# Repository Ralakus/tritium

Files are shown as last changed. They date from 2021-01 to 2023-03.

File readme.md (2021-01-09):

# Tritium Project
An open source RISC based balanced ternary computer

## What does balanced ternary mean?
Normal computers process data in binary which means two states, a one and a zero. Ternary is similar except operating on three states. In balanced ternary, there is a negative (i), neutral (0), and positive (1) which means numbers are naturally signed thus simplifying the architecture and general logic. Ternary also has the best radix efficiency for any integer base of 1.0046 where binary is 1.0615 with base e 1.0000 being the most efficient. A 'trit' is the ternary analogue of a bit which stores an i,0, or 1. 

## Has this been done before?
There are many projects similar to this but they either haven't gone very far, closed source, or dead. The main inspiration for this computer is the Russian Setun computer, more specifically the Setun-70 which has an 18 trit word and 81 words of memory with a magnetic drum holding more memory. 

## Variants
9, 27, 54, and maybe even 81 trit word variants will be made with a similar architecture. The 9 trit architecture being dubbed 'Tritium-9' will be made first as an experiment and prototype.

## Directory Structure
* architecture - contains documentation about the architecture of each tritium variant
* pcbs - contains all schematics and each revision of the custom pcb designs
* simulation - contains tests setup to simulate basic logic and other various circuitry test using ngspice
* tritium - contains the overall schematic of each tritium variant

## Tritium-9
### Design Goals
* Around or less than $250
* iiiiiiii to i11111111 being binary EEPROM to run a program off of with 0iiiiiiii to 111111111 being SRAM thus having the full 19683 tryte address space
* Have the ability to communicate with binary components
* Use easily sourcable parts

### Current Status
Tested each rev.0 pcb and posted results. Continuing on designing the alu

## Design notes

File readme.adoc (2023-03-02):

= Tritium Project
An open source RISC based balanced ternary computer research project

== This is a research project
This project is not fully intended to get a perfectly functional computer out to the market, but rather, it is intended to get the concept of ternary computing out to the public so more people will start researching ternary computing as an alternative to binary computing. 

== What does balanced ternary mean?
Normal computers process data in binary which means two states, a one and a zero. Ternary is similar except operating on three states. In balanced ternary, there is a negative (i), neutral (0), and positive (1) which means numbers are naturally signed thus simplifying the architecture and general logic. Ternary also has the best radix efficiency for any integer base of 1.0046 where binary is 1.0615 with base e, 1.0000 being the most efficient. A 'trit' is the ternary analogue of a bit which stores an i (-1), 0, or 1. 

== Has this been done before?
There are many projects similar to this but they either haven't gone very far, closed source and secretive, or dead. The main inspiration for this project is the Russian Setun computer, more specifically the Setun-70 which has an 18 trit word and 81 words of memory with a magnetic drum holding more memory. 

== Directory Structure
* docs - contains documentation on the project and lab results
* kicad - contains the kicad project files for each part
** components - contains all complex multigate circuits
** gates - contains all ternary gates and their panelized PCBs
** logic - contains logical schematics of circuits using logic gates instead of transistors
* library - contains all of the kicad libraries such as the footprints, spice models, and symbols

== Possible final computer variants
=== Tritium-6
A 6-trit computer that is cheap and simple to make where the instructions more closely resemble microcode rather than instructions.

==== Design Goals
* Around or less than $250 in components
* Have the ability to communicate with binary components
* Use easily sourcable parts
* One clock cycle per instruction

=== Tritium-27
A full scale computer that mirrors RISC-V in capability and instruction set.

==== Design Goals
* Around or less than $1000 in components
* Have the ability to communicate with binary components
* Use easily sourcable parts

== Current Status
The gates from OSHPark came but I've hit a bit of a time and financial crunch so I don't quite have the time to work on the physical part of the project. I'm currently working with a local college professor to write up a better ISA than the previous versions for a machine that I could follow that wouldn't be too expensive to implement. I've decided that the decoding logic for the control module may be too expensive to implement so I will see if I can use a binary EEPROM using encoded balanced ternary as a lookup table and then convert the inputs back to native balanced ternary.

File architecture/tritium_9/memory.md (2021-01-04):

# Tritium-9 Memory Mapping

## Memory regions
There are three memory regions:
* iiiiiiiii to i11111111 is mapped to the EEPROM and memory mapped IO
* 0iiiiiiii to 011111111 is mapped to persistent user usable RAM
* 1iiiiiiii to 111111111 is mapped to a memory page

## Memory pages
The page is controlled by the control register `page`. The pages can be mapped to any hardware thus giving lots of expandability outside of the 9-trit address space.

## RAM
As a first prototype, all RAM will be static RAM due to the low quantity needed but in the future, DRAM will be experimented with and possibly a native ternary DRAM module will be developed

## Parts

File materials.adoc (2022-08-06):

= Materials used in project

== PCB Manufacturing
Custom PCBs through OSHPark

== Power Supply
Meanwell RT-50A

== Gates
Complementary Pair MOSFET - BSS8402DW-7-F +
12k 0603 SMD Resistors

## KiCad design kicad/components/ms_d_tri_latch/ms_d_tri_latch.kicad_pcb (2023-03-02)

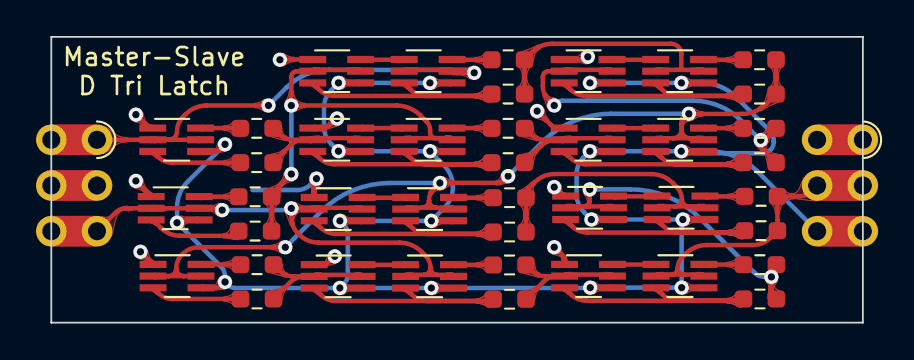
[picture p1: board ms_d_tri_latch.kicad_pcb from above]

Board: 2 copper layers, 45.1 x 15.9 mm, 43 parts (0 on the bottom side), 45 nets.

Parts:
J1, J2: Conn_01x03; Hybrid_Castellation_1x03_P2.54
Q1, Q2, Q3, Q4, Q5, Q6, Q7, Q8, Q9, Q10, Q11, Q12, Q13, Q14, Q15, Q16, Q17, Q18, Q19: BSS8402DW-7-F; SOT-363_SC-70-6_Handsoldering
R1, R2, R3, R4, R5, R6, R7, R8, R9, R10, R11, R12, R13, R14, R15, R16, R17, R18, R19, R20, R21, R22: 12k; R_0603_1608Metric_Pad0.98x0.95mm_HandSolder

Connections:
/Inverter2/Nti: Q19.6 (D), R22.2
/Inverter2/Out: Q14.2 (G), Q14.5 (G), Q15.2 (G), Q15.5 (G), R21.2, R22.1
/Inverter2/Pti: Q19.3 (D), R21.1
/d_latch1/Antimin4/B: Q3.2 (G), Q3.5 (G), R19.2, R20.1
/d_latch1/Antimin5/Out: Q4.2 (G), Q4.5 (G), R7.2, R8.1
/d_latch1/Antimin7/B: Q18.2 (G), Q18.5 (G), R1.2, R2.1
/d_latch1/Inverter1/Nti: Q1.6 (D), R2.2
/d_latch1/Inverter1/Pti: Q1.3 (D), R1.1
/d_latch1/~Q: Q5.2 (G), Q5.5 (G), R3.2, R4.1
/d_latch/Antimin4/B: Q10.2 (G), Q10.5 (G), R17.2, R18.1
/d_latch/Antimin5/Out: Q11.2 (G), Q11.5 (G), R15.2, R16.1
/d_latch/Antimin7/B: Q16.2 (G), Q16.5 (G), R9.2, R10.1
/d_latch/Inverter1/Nti: Q8.6 (D), R10.2
/d_latch/Inverter1/Pti: Q8.3 (D), R9.1
/d_latch/Q: Q1.2 (G), Q1.5 (G), Q6.2 (G), Q6.5 (G), Q9.2 (G), Q9.5 (G), R13.2, R14.1
/d_latch/~Q: Q12.2 (G), Q12.5 (G), R11.2, R12.1
D: J1.1, Q8.2 (G), Q8.5 (G), Q13.2 (G), Q13.5 (G)
Enable: J1.3, Q7.2 (G), Q7.5 (G), Q17.2 (G), Q17.5 (G), Q19.2 (G), Q19.5 (G)
unnamed: Q2.1 (S), Q3.6 (D)
unnamed: Q2.3 (D), Q3.3 (D), R3.1
unnamed: Q2.6 (D), R4.2
unnamed: Q4.1 (S), Q5.6 (D)
unnamed: Q4.3 (D), Q5.3 (D), R5.1
unnamed: Q4.6 (D), R6.2
unnamed: Q6.1 (S), Q7.6 (D)
unnamed: Q6.3 (D), Q7.3 (D), R7.1
unnamed: Q6.6 (D), R8.2
unnamed: Q9.6 (D), R12.2
unnamed: Q9.3 (D), Q10.3 (D), R11.1
unnamed: Q9.1 (S), Q10.6 (D)
unnamed: Q11.1 (S), Q12.6 (D)
unnamed: Q11.3 (D), Q12.3 (D), R13.1
unnamed: Q11.6 (D), R14.2
unnamed: Q13.1 (S), Q14.6 (D)
unnamed: Q13.3 (D), Q14.3 (D), R15.1
unnamed: Q13.6 (D), R16.2
unnamed: Q15.1 (S), Q16.6 (D)
unnamed: Q15.3 (D), Q16.3 (D), R17.1
unnamed: Q15.6 (D), R18.2
unnamed: Q17.1 (S), Q18.6 (D)
unnamed: Q17.3 (D), Q18.3 (D), R19.1
unnamed: Q17.6 (D), R20.2
Q: J2.2, Q2.2 (G), Q2.5 (G), R5.2, R6.1
VDD: J2.3, Q1.4 (S), Q2.4 (S), Q3.4 (S), Q4.4 (S), Q5.4 (S), Q6.4 (S), Q7.4 (S), Q8.4 (S), Q9.4 (S), Q10.4 (S), Q11.4 (S), Q12.4 (S), Q13.4 (S), Q14.4 (S), Q15.4 (S), Q16.4 (S), Q17.4 (S), Q18.4 (S), Q19.4 (S)
VSS: J1.2, J2.1, Q1.1 (S), Q3.1 (S), Q5.1 (S), Q7.1 (S), Q8.1 (S), Q10.1 (S), Q12.1 (S), Q14.1 (S), Q16.1 (S), Q18.1 (S), Q19.1 (S)

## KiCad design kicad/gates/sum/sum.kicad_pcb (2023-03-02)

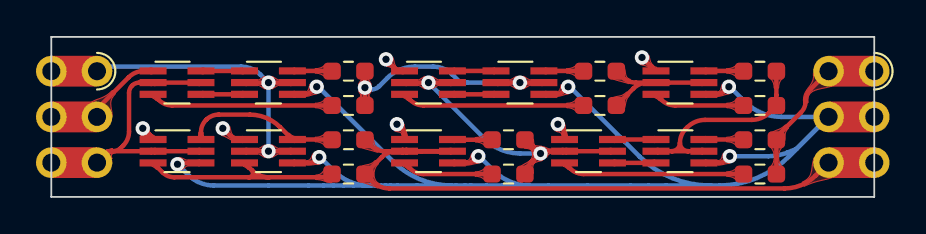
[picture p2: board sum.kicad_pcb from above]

Board: 2 copper layers, 45.7 x 8.9 mm, 24 parts (0 on the bottom side), 28 nets.

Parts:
J1, J2: Conn_01x03; Hybrid_Castellation_1x03_P2.54
Q1, Q2, Q3, Q4, Q5, Q6, Q7, Q8, Q9, Q10: BSS8402DW-7-F; SOT-363_SC-70-6_Handsoldering
R1, R2, R3, R4, R5, R6, R7, R8, R9, R10, R11, R12: 12k; R_0603_1608Metric_Pad0.98x0.95mm_HandSolder

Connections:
/Inverter BL/Nti: Q8.6 (D), R10.2
/Inverter BL/Out: Q4.2 (G), Q4.5 (G), Q6.2 (G), Q6.5 (G), R9.2, R10.1
/Inverter BL/Pti: Q8.3 (D), R9.1
/Inverter M/In: Q7.2 (G), Q7.5 (G), R3.2, R4.1
/Inverter M/Nti: Q7.6 (D), R8.2
/Inverter M/Out: Q5.2 (G), Q5.5 (G), R7.2, R8.1
/Inverter M/Pti: Q7.3 (D), R7.1
/NAny M/A: Q3.2 (G), Q3.5 (G), R1.2, R2.1
A: J1.1, Q1.2 (G), Q1.5 (G), Q9.2 (G), Q9.5 (G)
B: J1.3, Q2.2 (G), Q2.5 (G), Q10.2 (G), Q10.5 (G)
unnamed: Q1.1 (S), Q2.6 (D)
unnamed: Q1.3 (D), Q2.4 (S)
unnamed: Q1.6 (D), R2.2
unnamed: Q2.3 (D), R1.1
unnamed: Q3.1 (S), Q4.6 (D)
unnamed: Q3.3 (D), Q4.4 (S)
unnamed: Q3.6 (D), R4.2
unnamed: Q4.3 (D), R3.1
unnamed: Q5.1 (S), Q6.6 (D)
unnamed: Q5.3 (D), Q6.4 (S)
unnamed: Q5.6 (D), R6.2
unnamed: Q6.3 (D), R5.1
unnamed: Q9.3 (D), Q10.3 (D), R11.1
unnamed: Q9.6 (D), Q10.6 (D), R12.2
Sum: J2.1, R5.2, R6.1
VDD: J2.2, Q1.4 (S), Q3.4 (S), Q5.4 (S), Q7.4 (S), Q8.4 (S), Q9.4 (S), Q10.4 (S)
VSS: J1.2, Q2.1 (S), Q4.1 (S), Q6.1 (S), Q7.1 (S), Q8.1 (S), Q9.1 (S), Q10.1 (S)
~Carry: J2.3, Q8.2 (G), Q8.5 (G), R11.2, R12.1

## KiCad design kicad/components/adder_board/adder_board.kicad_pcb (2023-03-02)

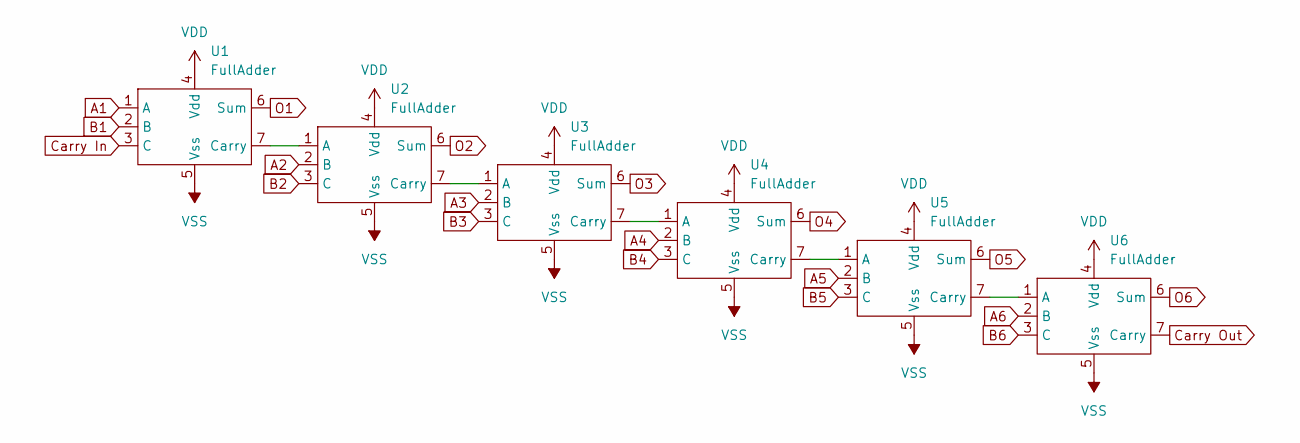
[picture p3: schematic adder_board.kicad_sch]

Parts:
U1, U2, U3, U4, U5, U6: FullAdder

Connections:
A1: U1.1 (A)
A2: U2.2 (B)
A3: U3.2 (B)
A4: U4.2 (B)
A5: U5.2 (B)
A6: U6.2 (B)
B1: U1.2 (B)
B2: U2.3 (C)
B3: U3.3 (C)
B4: U4.3 (C)
B5: U5.3 (C)
B6: U6.3 (C)
Carry In: U1.3 (C)
Carry Out: U6.7 (Carry)
unnamed: U1.7 (Carry), U2.1 (A)
unnamed: U2.7 (Carry), U3.1 (A)
unnamed: U3.7 (Carry), U4.1 (A)
unnamed: U4.7 (Carry), U5.1 (A)
unnamed: U5.7 (Carry), U6.1 (A)
O1: U1.6 (Sum)
O2: U2.6 (Sum)
O3: U3.6 (Sum)
O4: U4.6 (Sum)
O5: U5.6 (Sum)
O6: U6.6 (Sum)
VDD: U1.4 (Vdd), U2.4 (Vdd), U3.4 (Vdd), U4.4 (Vdd), U5.4 (Vdd), U6.4 (Vdd)
VSS: U1.5 (Vss), U2.5 (Vss), U3.5 (Vss), U4.5 (Vss), U5.5 (Vss), U6.5 (Vss)

Board: 2 copper layers, 6 parts (0 on the bottom side), 7 nets, no tracks yet.

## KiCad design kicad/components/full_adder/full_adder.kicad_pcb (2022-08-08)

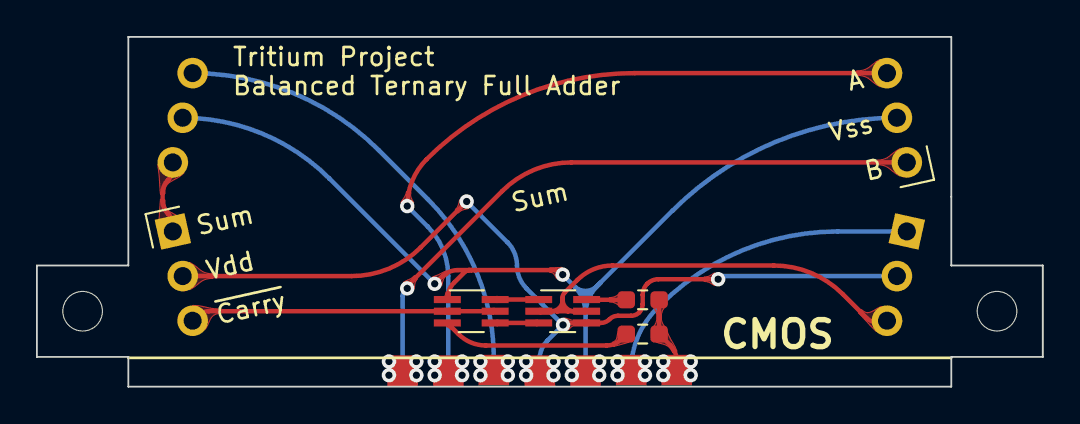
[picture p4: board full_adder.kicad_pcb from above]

Board: 2 copper layers, 55.9 x 19.4 mm, 6 parts (1 on the bottom side), 10 nets.

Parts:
Q1, Q2: BSS8402DW-7-F; SOT-363_SC-70-6_Handsoldering
R1, R2: 12k; R_0603_1608Metric_Pad0.98x0.95mm_HandSolder
U1, U2: Sum

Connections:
/NAny/A: Q1.2 (G), Q1.5 (G), U2.3 (~Carry)
/NAny/B: Q2.2 (G), Q2.5 (G), U1.3 (~Carry)
Carry: R1.2, R2.1
unnamed: Q1.1 (S), Q2.6 (D)
unnamed: Q1.3 (D), Q2.4 (S)
unnamed: Q1.6 (D), R2.2
unnamed: Q2.3 (D), R1.1
unnamed: U1.1 (Sum), U2.6 (B)
VDD: Q1.4 (S), U1.2 (Vdd), U2.2 (Vdd)
VSS: Q2.1 (S), U1.5 (Vss), U2.5 (Vss)

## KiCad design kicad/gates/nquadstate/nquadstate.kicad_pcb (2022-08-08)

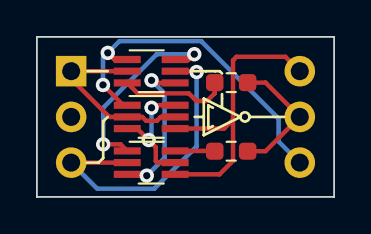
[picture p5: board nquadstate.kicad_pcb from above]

Board: 2 copper layers, 16.5 x 8.9 mm, 7 parts (0 on the bottom side), 10 nets.

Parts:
J1, J2: Conn_01x03; PinHeader_1x03_P2.54mm_Vertical_NoSilkscreen
Q1, Q2, Q3: BSS8402DW-7-F; SOT-363_SC-70-6_Handsoldering
R1, R2: 12k; R_0603_1608Metric_Pad0.98x0.95mm_HandSolder

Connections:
Gate: J1.1, Q1.2 (G), Q1.5 (G), Q3.2 (G)
In: J1.3, Q2.2 (G), Q3.5 (G)
unnamed: Q1.3 (D), Q1.6 (D), Q2.5 (G)
unnamed: Q2.1 (S), Q3.6 (D)
unnamed: Q2.3 (D), Q3.4 (S)
unnamed: Q2.6 (D), R2.2
unnamed: Q3.3 (D), R1.1
Out: J2.2, R1.2, R2.1
VDD: J2.1, Q1.4 (S), Q2.4 (S)
VSS: J2.3, Q1.1 (S), Q3.1 (S)

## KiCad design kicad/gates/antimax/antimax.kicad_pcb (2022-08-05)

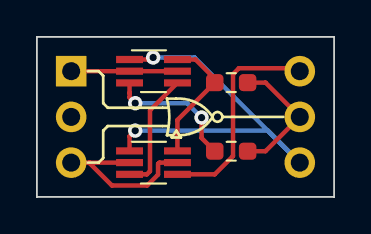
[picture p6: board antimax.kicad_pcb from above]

Board: 2 copper layers, 16.5 x 8.9 mm, 6 parts (0 on the bottom side), 8 nets.

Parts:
J1, J2: Conn_01x03; PinHeader_1x03_P2.54mm_Vertical_NoSilkscreen
Q1, Q2: BSS8402DW-7-F; SOT-363_SC-70-6_Handsoldering
R1, R2: 12k; R_0603_1608Metric_Pad0.98x0.95mm_HandSolder

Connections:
A: J1.3, Q1.2 (G), Q1.5 (G)
B: J1.1, Q2.2 (G), Q2.5 (G)
unnamed: Q1.3 (D), Q2.4 (S)
unnamed: Q1.6 (D), Q2.6 (D), R2.2
unnamed: Q2.3 (D), R1.1
Out: J2.2, R1.2, R2.1
VDD: J2.1, Q1.4 (S)
VSS: J2.3, Q1.1 (S), Q2.1 (S)

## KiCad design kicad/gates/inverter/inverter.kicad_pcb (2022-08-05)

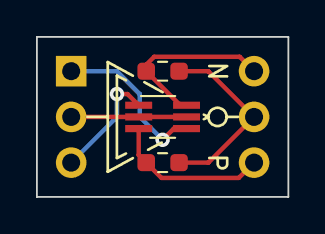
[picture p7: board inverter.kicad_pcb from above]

Board: 2 copper layers, 14.0 x 8.9 mm, 5 parts (0 on the bottom side), 6 nets.

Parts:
J1, J2: Conn_01x03; PinHeader_1x03_P2.54mm_Vertical_NoSilkscreen
Q1: BSS8402DW-7-F; SOT-363_SC-70-6_Handsoldering
R1, R2: 12k; R_0603_1608Metric_Pad0.98x0.95mm_HandSolder

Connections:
In: J1.2, Q1.2 (G), Q1.5 (G)
Nti: J2.1, Q1.6 (D), R2.2
Out: J2.2, R1.2, R2.1
Pti: J2.3, Q1.3 (D), R1.1
VDD: J1.1, Q1.4 (S)
VSS: J1.3, Q1.1 (S)

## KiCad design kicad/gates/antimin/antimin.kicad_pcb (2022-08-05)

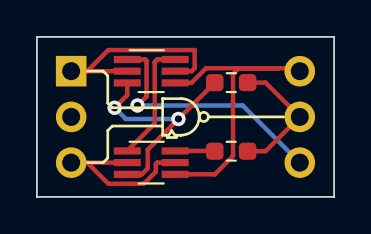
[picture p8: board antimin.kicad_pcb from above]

Board: 2 copper layers, 16.5 x 8.9 mm, 6 parts (0 on the bottom side), 8 nets.

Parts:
J1, J2: Conn_01x03; PinHeader_1x03_P2.54mm_Vertical_NoSilkscreen
Q1, Q2: BSS8402DW-7-F; SOT-363_SC-70-6_Handsoldering
R1, R2: 12k; R_0603_1608Metric_Pad0.98x0.95mm_HandSolder

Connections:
A: J1.3, Q1.2 (G), Q1.5 (G)
B: J1.1, Q2.2 (G), Q2.5 (G)
unnamed: Q1.1 (S), Q2.6 (D)
unnamed: Q1.3 (D), Q2.3 (D), R1.1
unnamed: Q1.6 (D), R2.2
Out: J2.2, R1.2, R2.1
VDD: J2.1, Q1.4 (S), Q2.4 (S)
VSS: J2.3, Q2.1 (S)

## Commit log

2020-12-07 binary converter
    [and.sch, antimax.sch, binary_conversion.kicad_pcb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]
2020-12-18 ternary adders, switches, and cyclers
    [addition.kicad_pcb, addition.sch, alu.sch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]
2020-12-18 remove nconensus gate from sum gate, removed .sch-bak and cache files
    [addition.sch, full_adder.sch, half_adder.sch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]
2020-12-18 lowered transistor count for sum gate
    [addition.sch, full_adder.sch, half_adder.sch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]
2020-12-18 added flat schematic for full adder
    [addition.sch, flat_schematic.sch, full_adder.sch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]
2020-12-20 added pcbs for each gate
    [antimax.kicad_pcb, antimax.sch, antimin.kicad_pcb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]
2020-12-23 added KiCad library for ternary gates and went from header pins and sockets to castellated edge pcbs
    [alu.sch, analogue_switch.sch, and.sch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]
2020-12-27 added ngspice models for each gate symbol
    [addition.sch, antimax.sch, full_adder.sch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]
2020-12-27 updated readme.md and materials.md
2020-12-27 update readme.md to include current project status
    [addition.sch, and.sch, binary_conversion.sch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]
2020-12-28 added edge triggered triflop
    [edge_detection.kicad_pcb, edge_detection.sch, triflop.kicad_pcb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]
2020-12-28 added block diagram architecture
    [alu.sch, clock.sch, control_register.sch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]
2021-01-01 re-organized project directory and started work on ALU pcb
    [addition.sch, analogue_switch.sch, antimax.kicad_pcb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]
2021-01-01 started pure ternary alu
    [adder.sch, addition.sch, any.sch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]
2021-01-03 designed alu schematic
    [adder.sch, alu.kicad_pcb, alu.sch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]
2021-01-03 layed out alu pcb
    [adder.sch, alu.kicad_pcb, alu.sch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]
2021-01-03 routed adder traces
    [alu.kicad_pcb, alu.sch, power_switch.sch]
2021-01-04 remake alu to be modular and updated isa to add control register and memory paging
    [adder.kicad_pcb, adder.sch, alu.kicad_pcb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]
2021-01-07 bss84 drain and source flipped
    [alu.kicad_pcb, analogue_switch.sch, antimax.kicad_pcb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]
2021-01-09 tested rev.0 pcbs and added results to doc
    [nany.kicad_pcb, nany.sch]
2021-01-09 added expected results to rev.0 pcb test
2021-01-10 completed adder module for alu
    [adder.kicad_pcb]
2021-01-10 completed adder module schematics
    [adder.sch, alu.sch, any.sch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]
2021-01-10 moved overall system schematic to architecture folder
    [adder.sch, alu.sch, clock.sch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]
2021-01-16 started fast addition experiments and tritium-6 architecture
    [adder.sch, any.kicad_pcb, fast_addition.kicad_pcb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]
2021-01-17 moved documentation from markdown to asciidoc
    [adder.kicad_pcb, adder.sch, alu.kicad_pcb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]
2021-02-08 added gate name to rev.2 pcbs and added clip gate
    [antimax.kicad_pcb, antimin.kicad_pcb, clip.kicad_pcb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]
2021-02-08 added rev.2 gerbers
2021-04-30 restructued project directory and added schematic pdfs
    [adder.kicad_pcb, adder.sch, alu.kicad_pcb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]
2021-05-17 added rev.3 gates
    [antimax.kicad_pcb, antimax.sch, antimin.kicad_pcb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]
2021-05-19 updated antimin rev.3 pcb to fix board size
    [antimin.kicad_pcb]
2021-05-20 updated materials.adoc
2022-08-05 project cleanup and restructure
    [adder.kicad_pcb, adder.sch, addition.kicad_pcb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]
2022-08-06 fixed sum logic gate schematic and simulation
    [panel.kicad_pcb, sum.kicad_sch]
2022-08-06 updated inverter logic symbol to match art on pcb and updated readme
    [sum.kicad_sch]
2022-08-06 added power supply to materials list
2022-08-08 created sum gate pcb and full adder pcb and analog consensus, min, and max logic gates
    [consensus.kicad_sch, full_adder.kicad_pcb, full_adder.kicad_sch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]
2022-08-08 deleted kicad cache files
2023-03-02 Update readme.adoc with current project status. Created master-slave D tri-latch gate
    [adder_board.kicad_pcb, adder_board.kicad_sch, and-or-invert.kicad_sch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]
